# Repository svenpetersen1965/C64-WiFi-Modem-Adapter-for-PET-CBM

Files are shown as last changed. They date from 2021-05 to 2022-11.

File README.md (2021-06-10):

# C64-WiFi-Modem-Adapter for the Commodore PET/CBM computers
This is an adapter for connecting a <a href="https://github.com/svenpetersen1965/C64-WiFi-Modem-User-Port">C64 WiFi-Modem</a> to the PET/CBM User Port.

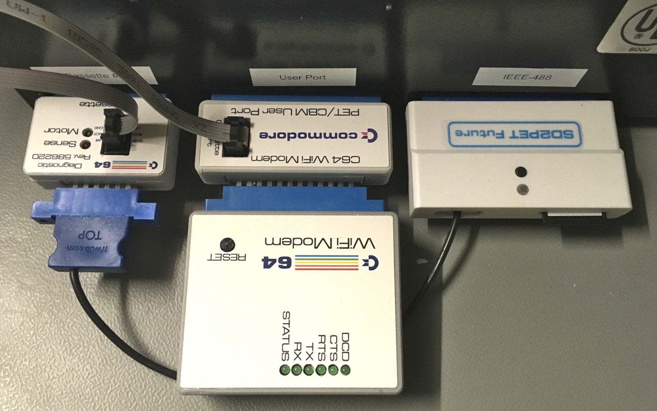
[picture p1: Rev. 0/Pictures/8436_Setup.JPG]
WiFi-modem on CBM8032


The power obtained from the Cassette Port via the <a href="https://github.com/svenpetersen1965/C64-Diagnostic-Rev.-586220-Harness/tree/master/Diag586220_Harness/Diag586220_Cassette_Port">Cassette Port Dongle</a> from the diagnostic harness for the C64.

The terminal program that was used for testing is <a href="https://github.com/ChartreuseK/PETTERM/releases">PETTERM0.5.0</a>

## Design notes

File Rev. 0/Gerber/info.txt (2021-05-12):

      
       Board: Wifi_Modem_PET_Adapter
       Rev.:  0
  
       Files:
       ======
  
       All Gerber files are generated in extended gerber format (RS274X)
       *.TOP        : Film top copper
       *.BOT        :  -"- bottom copper
       *.STC        :  -"- top soldermask 
       *.STS        :  -"- bottom soldermask
       *.PLC        :  -"- silk screen top
       *.DK         : Drills plated Through (Excellon)
       *.NDK        : Drills not plated Through (Excellon)
       *.OUT        : Board outline

       Board Size:
       ===========
       Length     :   54.0 mm
       Width      :   48.0 mm
       Thickness  :   1.6 mm
       Material   :   FR 4
       Copper     :   35 um
       Surface    :   HASL
       
       Remarks:
       ========
       Width >= 8mil
       Distance >= 6mil
       Drill >= 0.35mm

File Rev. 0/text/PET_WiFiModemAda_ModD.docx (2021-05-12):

Commodore C64 WiFi-Modem PET Adapter Rev. 0
Module Description

The C64 WiFi-Modem Adapter for PET was made to connect the C64 WiFi-Modem (https://1200baud.wordpress.com/2017/03/04/build-your-own-9600-baud-c64-wifi-modem-for-20/), (project on github.com) (https://github.com/svenpetersen1965/C64-WiFi-Modem-User-Port) to the User Port of the Commodore PET or CBM.


Figure 1: Setup with cassette dongle, user port adapter, WiFi modem and SD2PET

The wiring is done according to the requirements of the terminal program PETTERM 0.5.0 (https://github.com/ChartreuseK/PETTERM/releases).

Modem Signal | PET User Port | Direction (seen from PET) | PET UP Pin | C64 Modem | Modem Pin
TxD | CA1 & PA0 | input | B & C | Flag & PB0 | B & C
RxD | CB2 | output | M | PA2 | M

The signals RTS, DCD and CTS are not used, neither by the modem nor by PETTERM.

To provide an upgrade in future, the unused PET User Port pins and the signals mentioned before, are connected to a pin header (for jumpering).

Pin | PET Userport | JP1 | JP1 | C64 WiFi Modem | Pin
D | PA1 | 13 | 14 | RTS | D
E | PA2 | 11 | 12 | - | -
F | PA3 | 9 | 10 | - | -
H | PA4 | 7 | 8 | DCD | H
J | PA5 | 5 | 6 | - | -
K | PA6 | 3 | 4 | CTS | K
L | PA7 | 1 | 2 | - | -

Since the PET User Port does not provide +5V for powering the modem, this voltage is tapped from the Cassette Port and a cassette port dongle (https://github.com/svenpetersen1965/C64-Diagnostic-Rev.-586220-Harness/tree/master/Diag586220_Harness/Diag586220_Cassette_Port), which is also used in the C64 Diagnostic Harness. The connection is achieved with a 2x3 pin header (J3) and a ribbon cable.

Signal | Pin | Pin | Signal
GND | 1 | 2 | +5V
- | 3 | 4 | -
- | 5 | 6 | -

There is also a barrel connector for the +5V (5.5/2.1mm), which is not recommended to use, since it might collide with an IEEE-488 port connector/device.

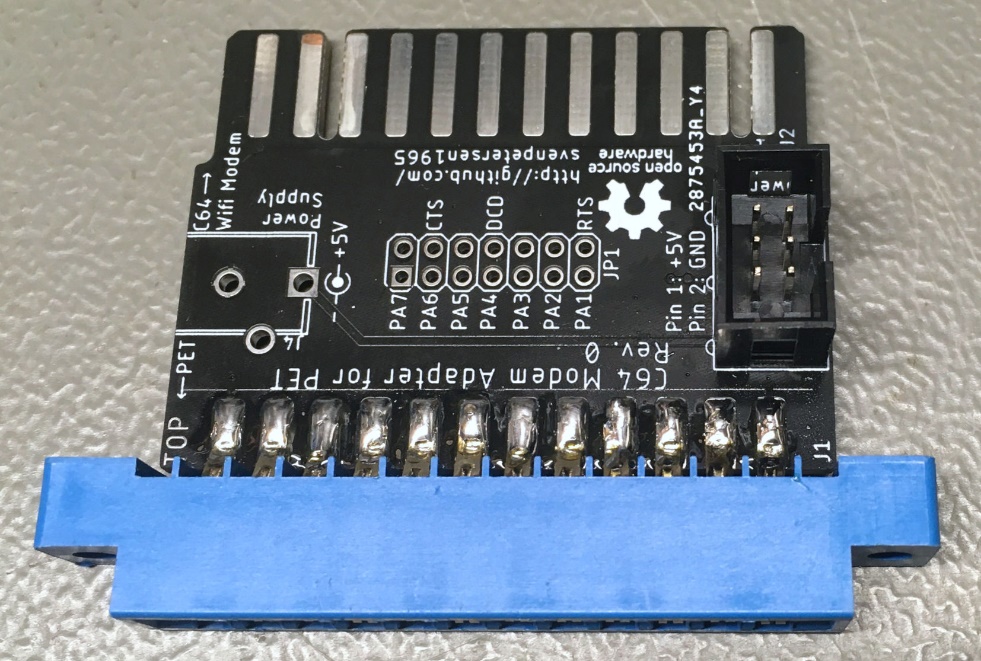
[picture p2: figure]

Figure 2: assembled PCB of the WiFi modem adapter

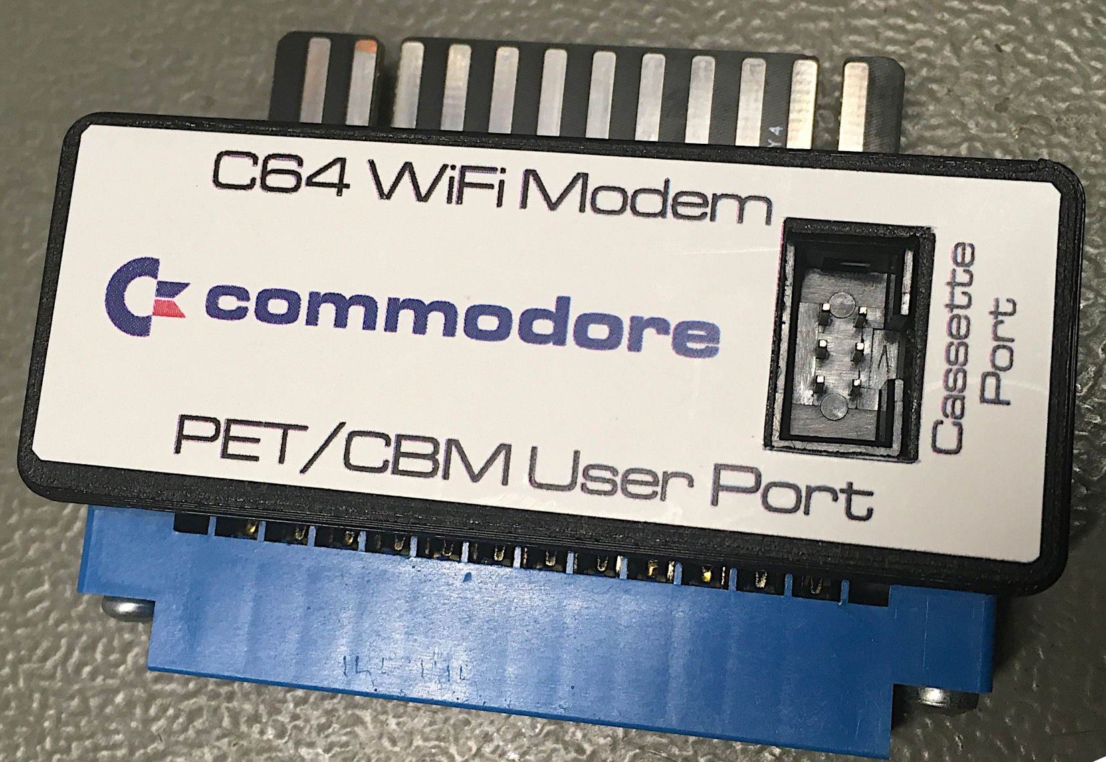
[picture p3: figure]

Figure 3: Adapter in 3D printed case

The screws recommended for the 3D printed case are

- 2x C2.9x9.5 DIN 7981 (for connecting bottom shell and top shell of the case)
- 2x C2.9x13 DIN 7981 (for attaching the edge connector to the bottom shell)

Other screws of approximately the same dimensions might work as well.

# Dimensions

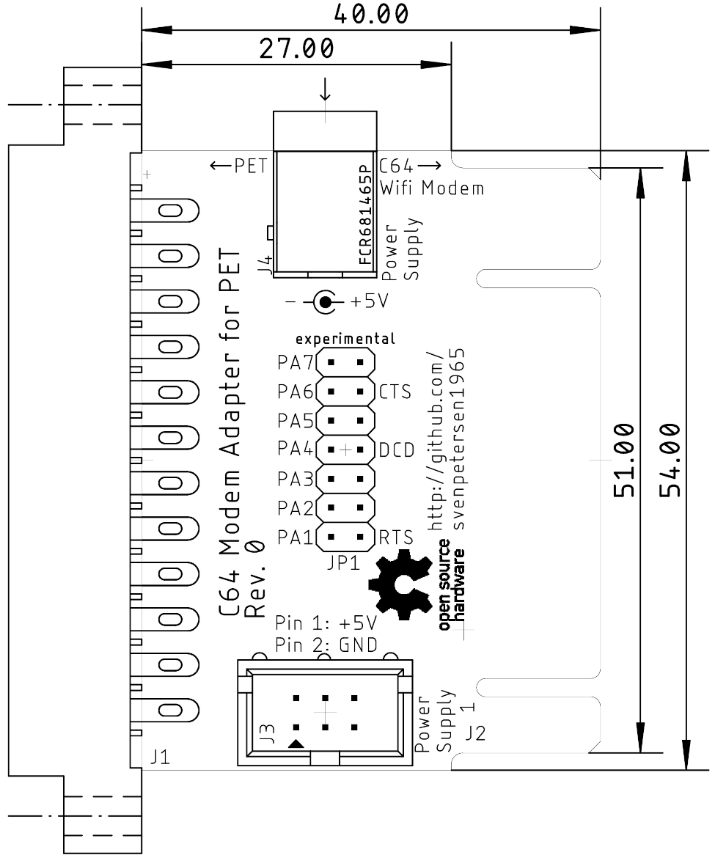
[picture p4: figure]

# Revision History

## Rev. 0

- Fully functional prototype

PET_WiFiModemAda_ModD.docx 12.05.2021 21:18 Drafted by Sven Petersen Page 2 of 2 Doc.-No.: 175-6-01-00

PET_WiFiModemAda_ModD.docx 12.05.2021 21:18 Drafted by Sven Petersen Page 1 of 1 Doc.-No.: 000-6-00-00

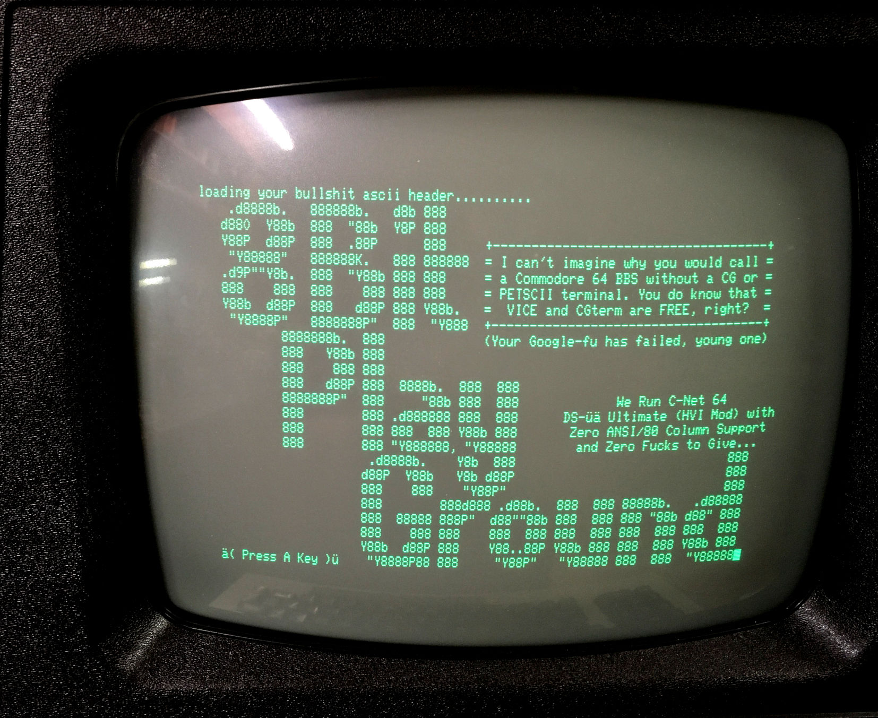
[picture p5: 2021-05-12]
Rev. 0/Pictures/8157_-_8bit_Playground.JPG

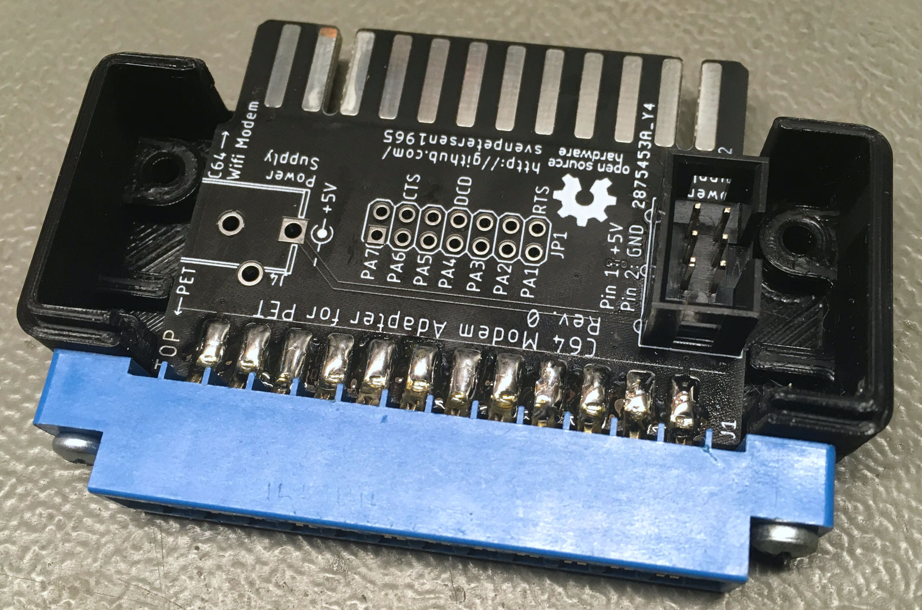
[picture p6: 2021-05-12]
Rev. 0/Pictures/8442_-_Adapter_in_bottom_sell.JPG

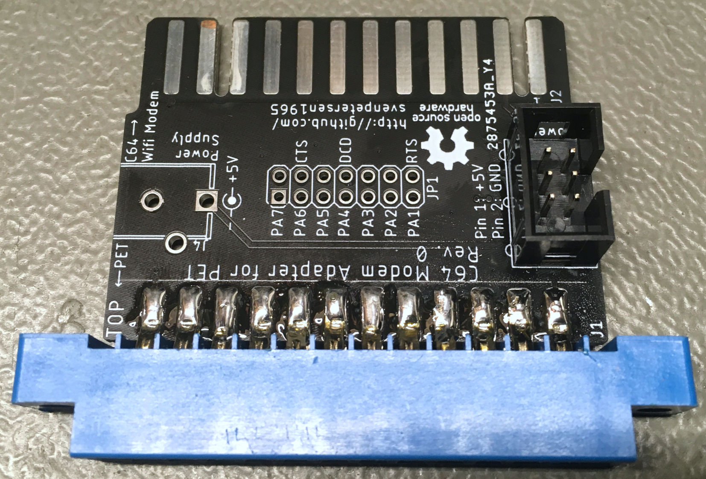
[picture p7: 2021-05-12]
Rev. 0/Pictures/8440_-_Adapter.JPG

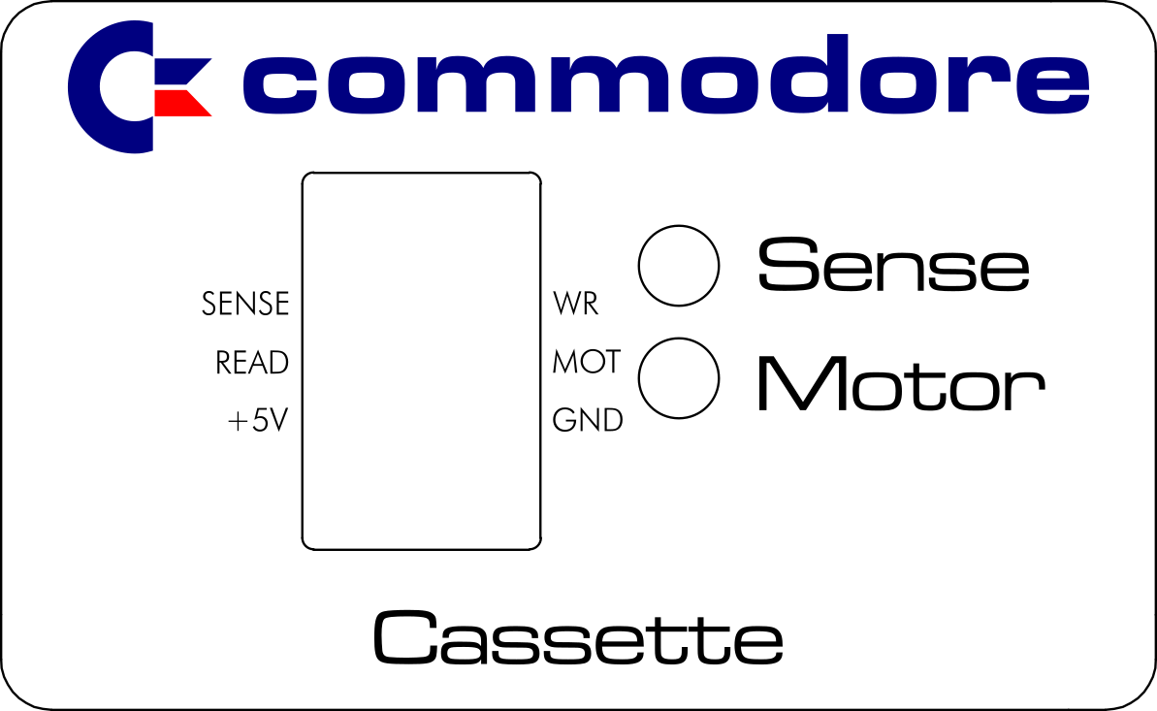
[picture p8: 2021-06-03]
3D-Case/Rev. 0/label/Cassette_Port_Dongle_Label.png

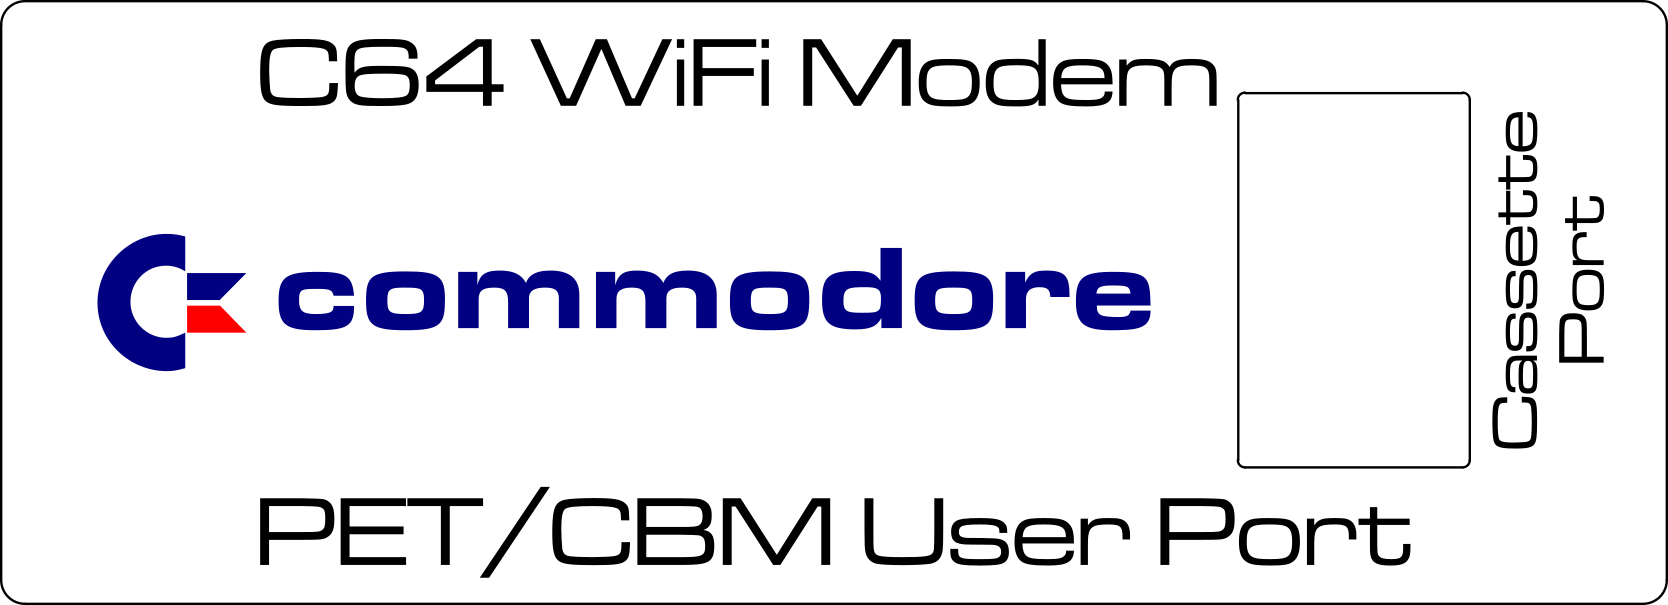
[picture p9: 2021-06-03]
3D-Case/Rev. 0/label/C64_WiFi_PET_Adapter_Label.png

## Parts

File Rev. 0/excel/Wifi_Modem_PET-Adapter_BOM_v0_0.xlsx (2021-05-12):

Commodore C64 Wifi-Modem PET Adapter Rev. 0
Bill of Material Rev. 0.0
Pos. | Qty | Value | Footprint | Ref.-No. | Comment
1 | 1 | 175-2-01-00 | 2 Layer | PCB Rev. 0 | 2 layer, Cu 35µ, HASL, 54.0mm x 40.0mm, 1.6mm FR4
2 | 1 | 2x3 box header, 2.54mm | 2X03WV | J3 | e.g. Reichelt WSL 6G
3 | 1 | 2x07, pinheader, 2.54mm | 2X07 | JP1 | Do not place
4 | 1 | FCR681465P | FCR681465P | J4 | Cliff. Do not place!
5 | 1 | Edge connector, 2x12, 3.96mm | USERPORT | J1 | edge connector, C64 user port, series 805

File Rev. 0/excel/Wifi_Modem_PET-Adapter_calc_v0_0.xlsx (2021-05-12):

Commodore C64 Wifi-Modem PET Adapter Rev. 0
Bill of Material Rev. 0.0
Pos. | Qty | Value | €/ea | € | Comment
1 | 1 | 175-2-01-00 | 1.00 € | 1.00 € | 2 layer, Cu 35µ, HASL, 54.0mm x 40.0mm, 1.6mm FR4
2 | 1 | 2x3 box header, 2.54mm | 0.25 € | 0.25 € | e.g. Reichelt WSL 6G
3 | 0 | 2x07, pinheader, 2.54mm | 0.32 € | 0.00 € | Do not place
4 | 0 | FCR681465P | 1.10 € | 0.00 € | Cliff. Do not place!
5 | 1 | Edge connector, 2x12, 3.96mm | 3.00 € | 3.00 € | edge connector, C64 user port, series 805
 |  | Total |  | 4.25 €

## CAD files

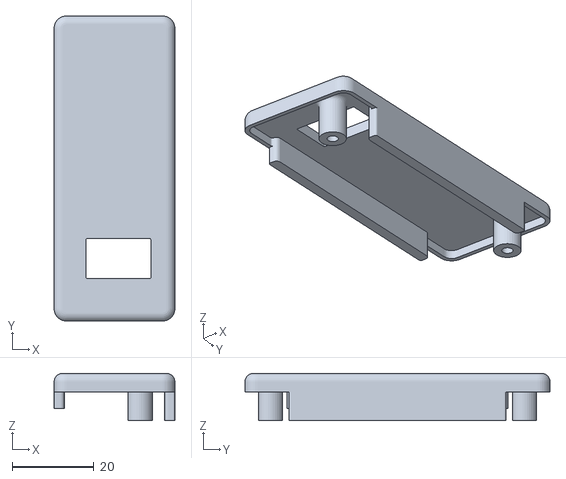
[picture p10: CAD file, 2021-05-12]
3D-Case/Rev. 0/stl/PETAda_top_shell.stl
29.5 x 74.5 x 11.5

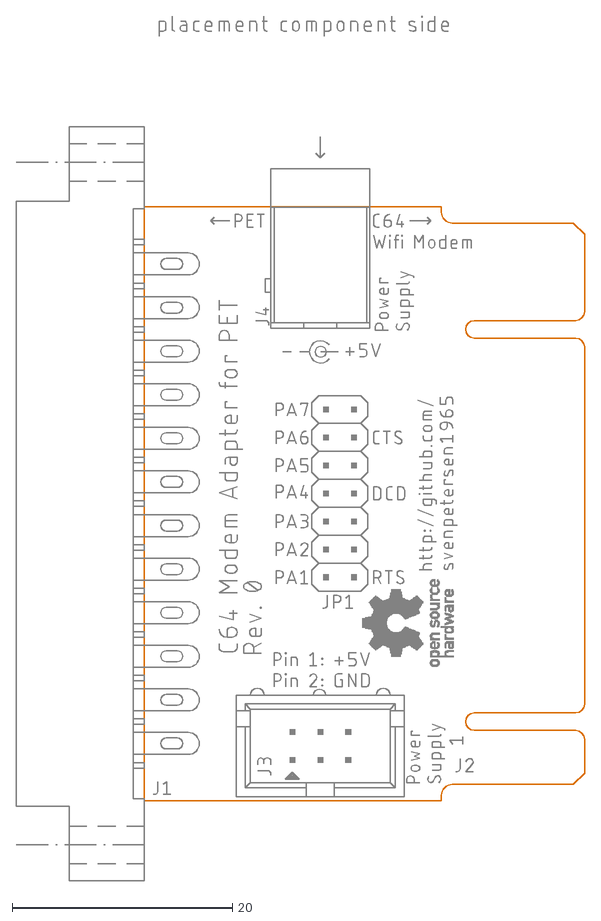
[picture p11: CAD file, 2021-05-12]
Rev. 0/dxf/Wifi_Modem_PET-Adapter.dxf
51.6 x 78.5

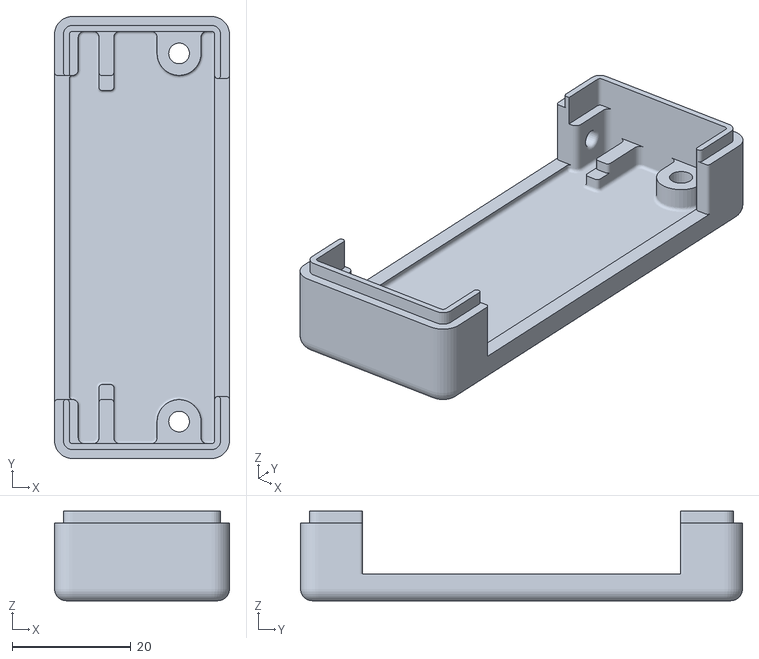
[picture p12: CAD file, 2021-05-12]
3D-Case/Rev. 0/stl/PETAda_bottom_shell.stl
29.5 x 74.5 x 15.1

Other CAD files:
3D-Case/Rev. 0/Fusion360/C64_Wifi_PET_adapter v4.f3d

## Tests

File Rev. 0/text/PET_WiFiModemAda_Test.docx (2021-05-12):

Commodore C64 WiFi-Modem PET Adapter Rev. 0
Testing

# Test Setup

The Test was conducted on a CBM8032 with a German character set, a C64 WiFi-Modem (like mentioned in Document 175-6-01-**), a Cassette Port dongle Rev. 1 and a C64 WiFi-Modem Adapter Rev. 0. The software PETTERM0-5-0 was stored on an SD-card in the SD2PET future.


Figure 1: Test Setup

The baud rate of the modem was set to 1200baud (this configuration was done and stored with the software CSMG2017 running on a C64).

# Test Execution

Several BBSes have been called. The WiFi-Modem has been fully operational at all time, the information transfer was correct.

# Conclusion

The WiFi-Modem Adapter is fully functional.


Figure 2: CBM8032 connected to the BBS 8Bit Playground

PET_WiFiModemAda_Test.docx 12.05.2021 21:54 Drafted by Sven Petersen Page 2 of 2 Doc.-No.: 175-6-02-00

PET_WiFiModemAda_Test.docx 12.05.2021 21:54 Drafted by Sven Petersen Page 1 of 1 Doc.-No.: 175-6-02-00

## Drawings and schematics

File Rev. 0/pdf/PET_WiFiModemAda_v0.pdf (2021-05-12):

# Project Documentation

## Commodore C64 Wifi-Modem PET Adapter

## Project number: 175

## Revision: 0

## Date: 10.03.2021

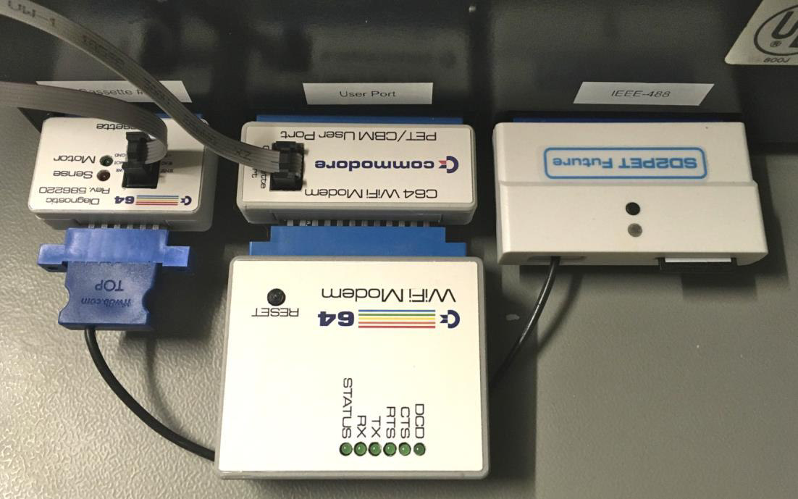
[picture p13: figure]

PET_WiFiModemAda_ModD.docx | | 12.05.2021 21:18
Drafted by Sven Petersen | Page 1 of 3 | Doc.-No.: 175-6-01-00

### Commodore C64 WiFi-Modem PET Adapter Rev. 0

### Module Description

The C64 WiFi-Modem Adapter for PET was made to connect the C64 WiFi-Modem (https://1200baud.wordpress.com/2017/03/04/build-your-own-9600-baud-c64-wifi-modem-for-20/), (https://1200baud.wordpress.com/2017/03/04/build-your-own-9600-baud-c64-wifi-modem-for-20/) (project on github.com) (https://github.com/svenpetersen1965/C64-WiFi-Modem-User-Port) to the User Port of the Commodore PET or CBM.

Figure 1: Setup with cassette dongle, user port adapter, WiFi modem and SD2PET

The wiring is done according to the requirements of the terminal program PETTERM 0.5.0. (https://github.com/ChartreuseK/PETTERM/releases)

Modem
Signal
PET User Port | Direction (seen from PET)

PET UP
Pin

C64 Modem Modem Pin

TxD | CA1 & PA0 | input | B & C | Flag & PB0 | B & C
RxD | CB2 | output | M | PA2 | M

The signals RTS, DCD and CTS are not used, neither by the modem nor by PETTERM.

To provide an upgrade in future, the unused PET User Port pins and the signals mentioned before, are connected to a pin header (for jumpering).

Pin PET Userport JP1 | JP1 C64 WiFi Modem Pin
D | PA1 | 13 | 14 | RTS | D
E | PA2 | 11 | 12 | - | -
F | PA3 | 9 | 10 | - | -
H | PA4 | 7 | 8 | DCD | H
J | PA5 | 5 | 6 | - | -
K | PA6 | 3 | 4 | CTS | K
L | PA7 | 1 | 2 | - | -

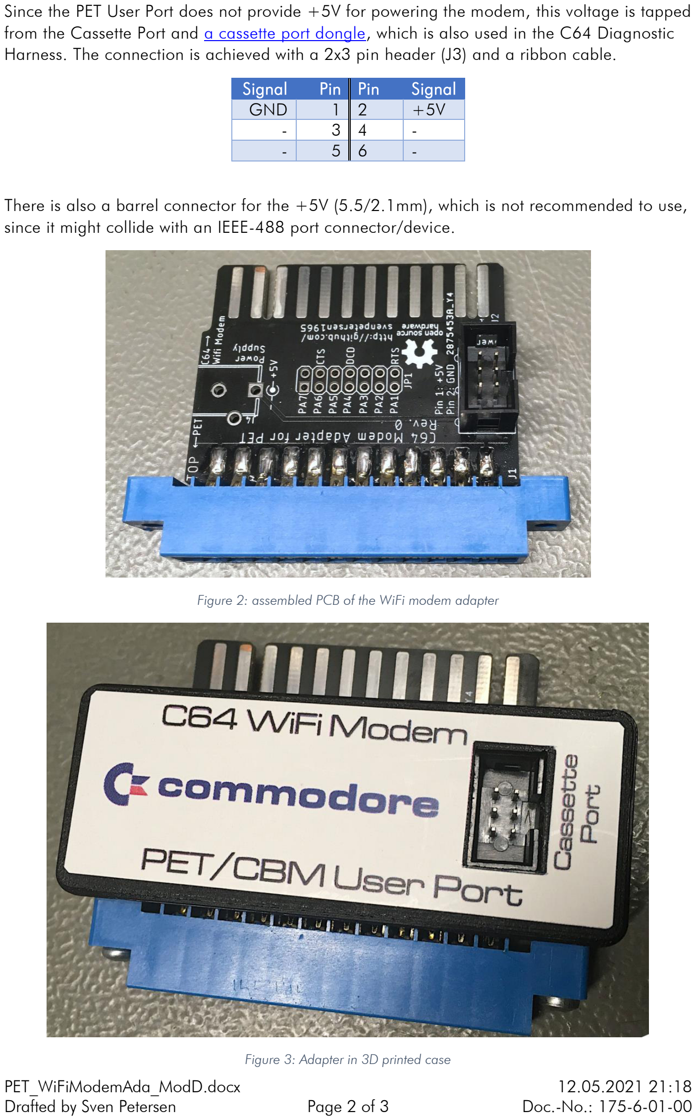
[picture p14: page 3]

PET_WiFiModemAda_ModD.docx | | 12.05.2021 21:18
Drafted by Sven Petersen | Page 2 of 3 | Doc.-No.: 175-6-01-00

Since the PET User Port does not provide +5V for powering the modem, this voltage is tapped from the Cassette Port and a cassette port dongle, (https://github.com/svenpetersen1965/C64-Diagnostic-Rev.-586220-Harness/tree/master/Diag586220_Harness/Diag586220_Cassette_Port) which is also used in the C64 Diagnostic Harness. The connection is achieved with a 2x3 pin header (J3) and a ribbon cable.

Signal Pin | Pin Signal
GND | 1 | 2 | +5V
- | 3 | 4 | -
- | 5 | 6 | -

There is also a barrel connector for the +5V (5.5/2.1mm), which is not recommended to use, since it might collide with an IEEE-488 port connector/device.

Figure 2: assembled PCB of the WiFi modem adapter

Figure 3: Adapter in 3D printed case

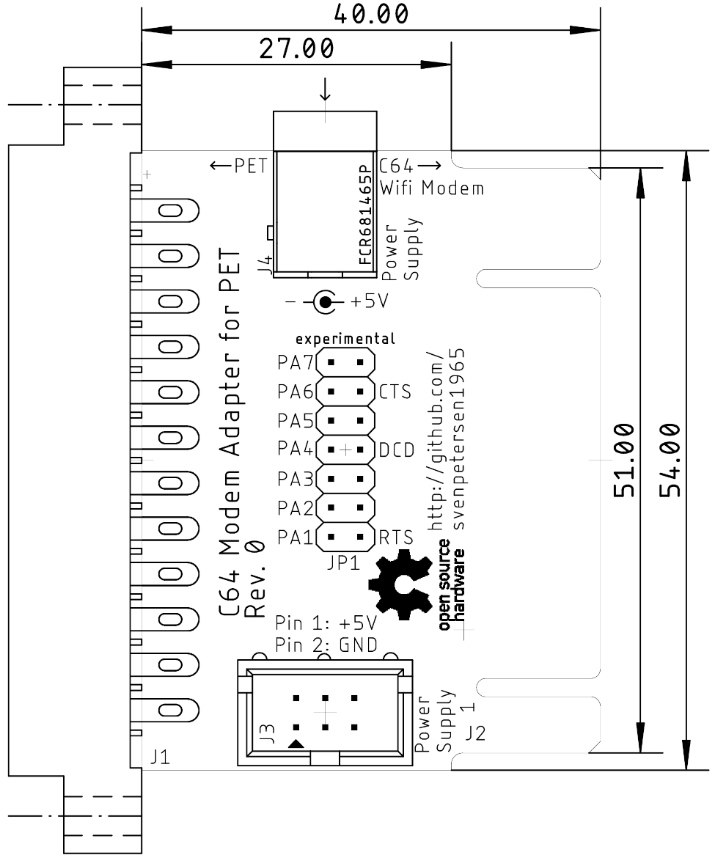
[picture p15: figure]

PET_WiFiModemAda_ModD.docx | | 12.05.2021 21:18
Drafted by Sven Petersen | Page 3 of 3 | Doc.-No.: 175-6-01-00

The screws recommended for the 3D printed case are

- 2x C2.9x9.5 DIN 7981 (for connecting bottom shell and top shell of the case)
- 2x C2.9x13 DIN 7981 (for attaching the edge connector to the bottom shell)

Other screws of approximately the same dimensions might work as well.

## Dimensions

## Revision History

### Rev. 0

- Fully functional prototype

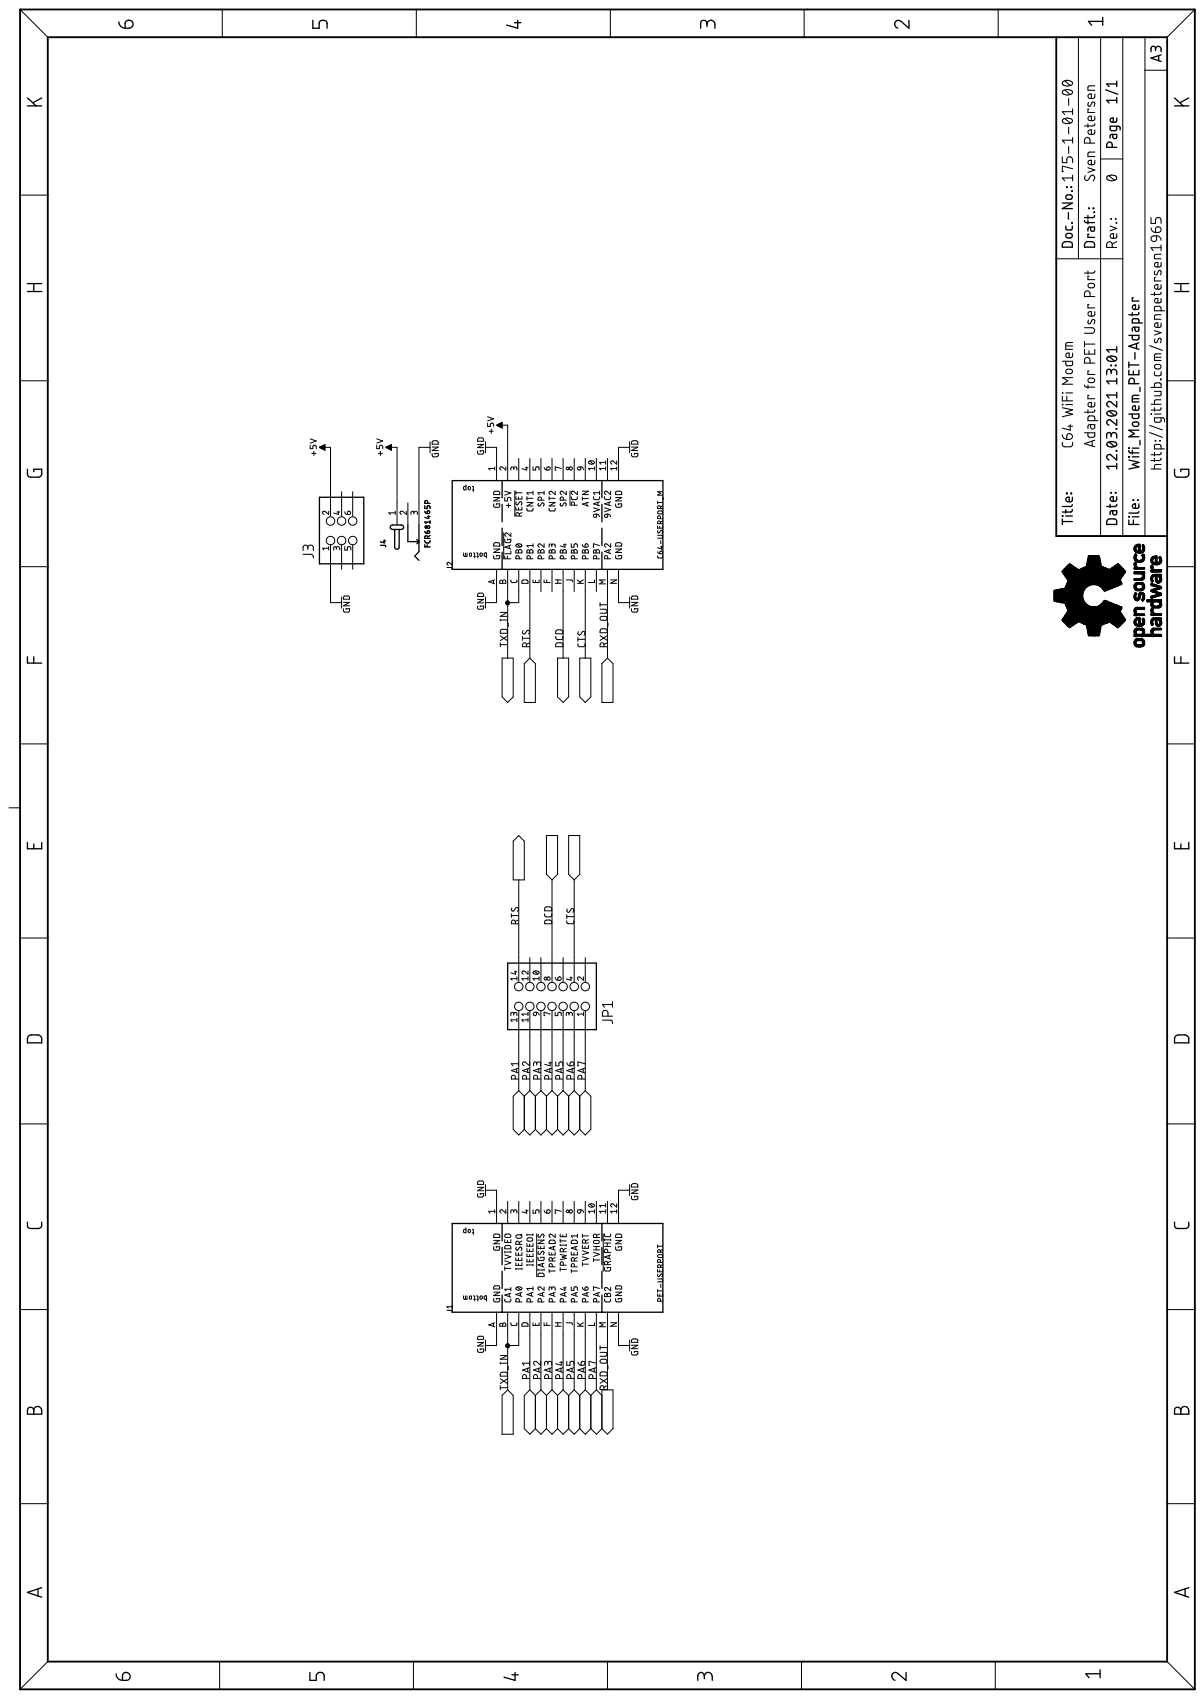
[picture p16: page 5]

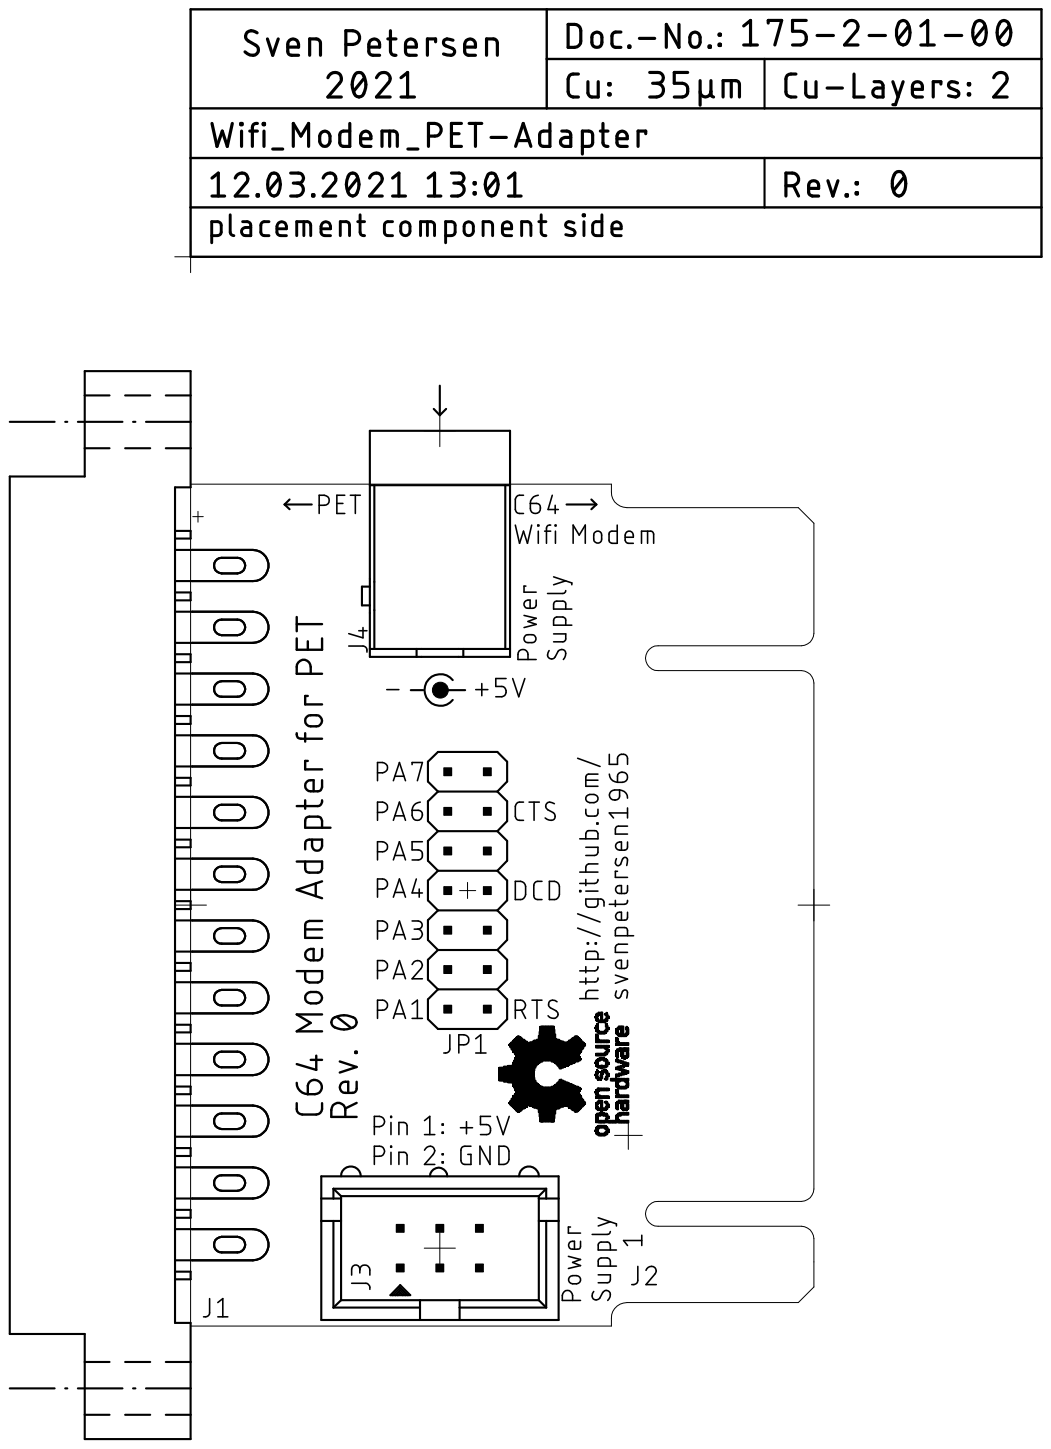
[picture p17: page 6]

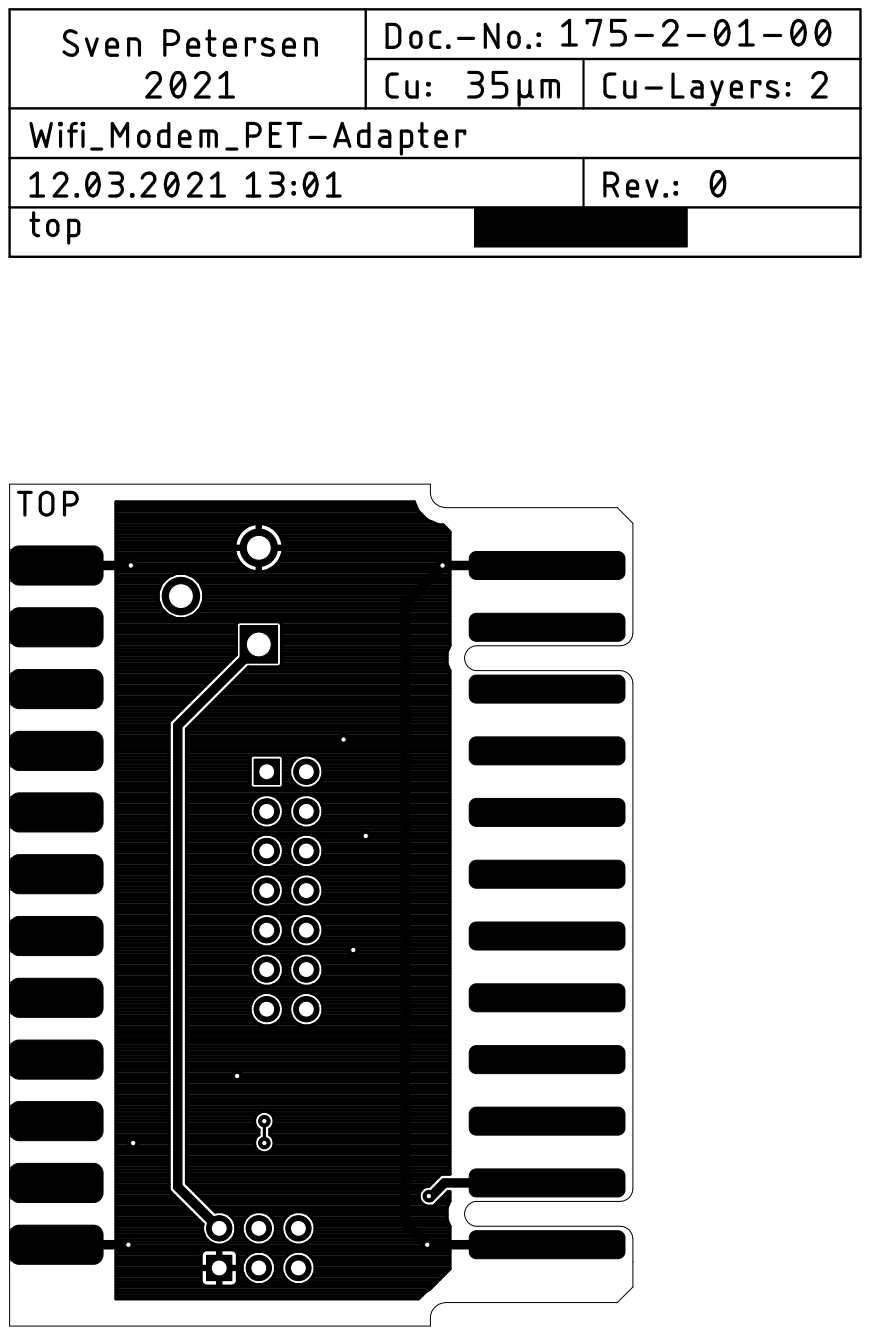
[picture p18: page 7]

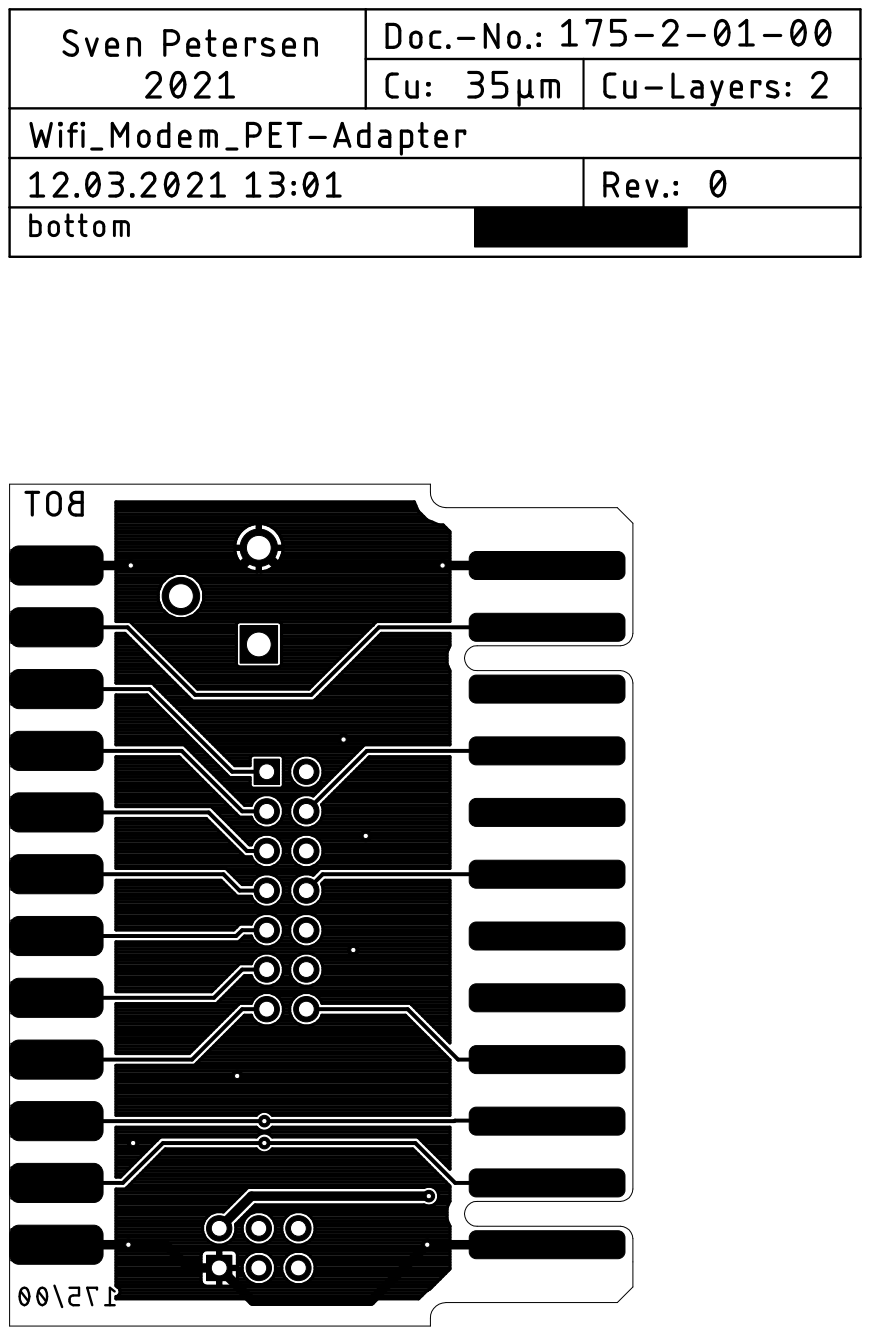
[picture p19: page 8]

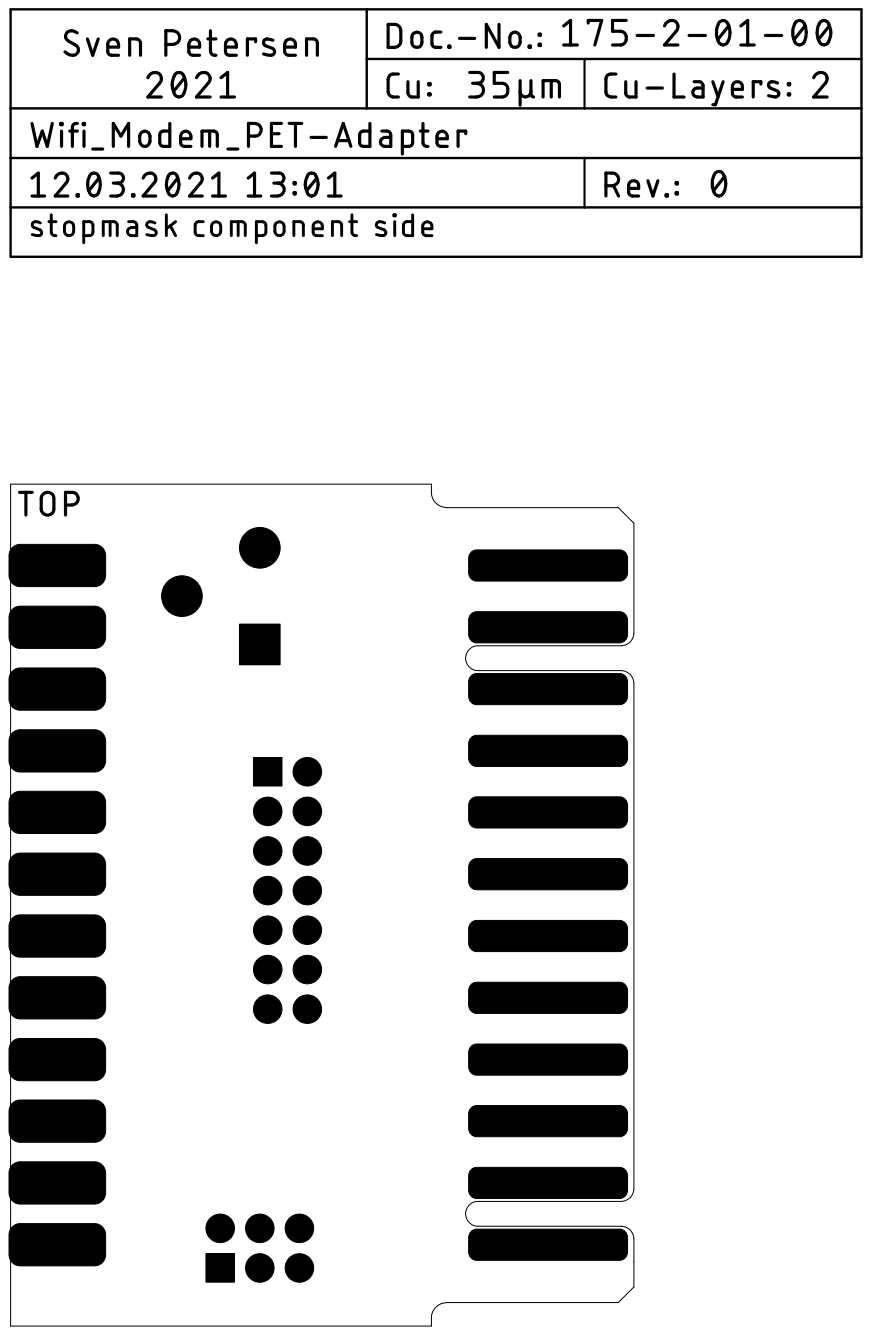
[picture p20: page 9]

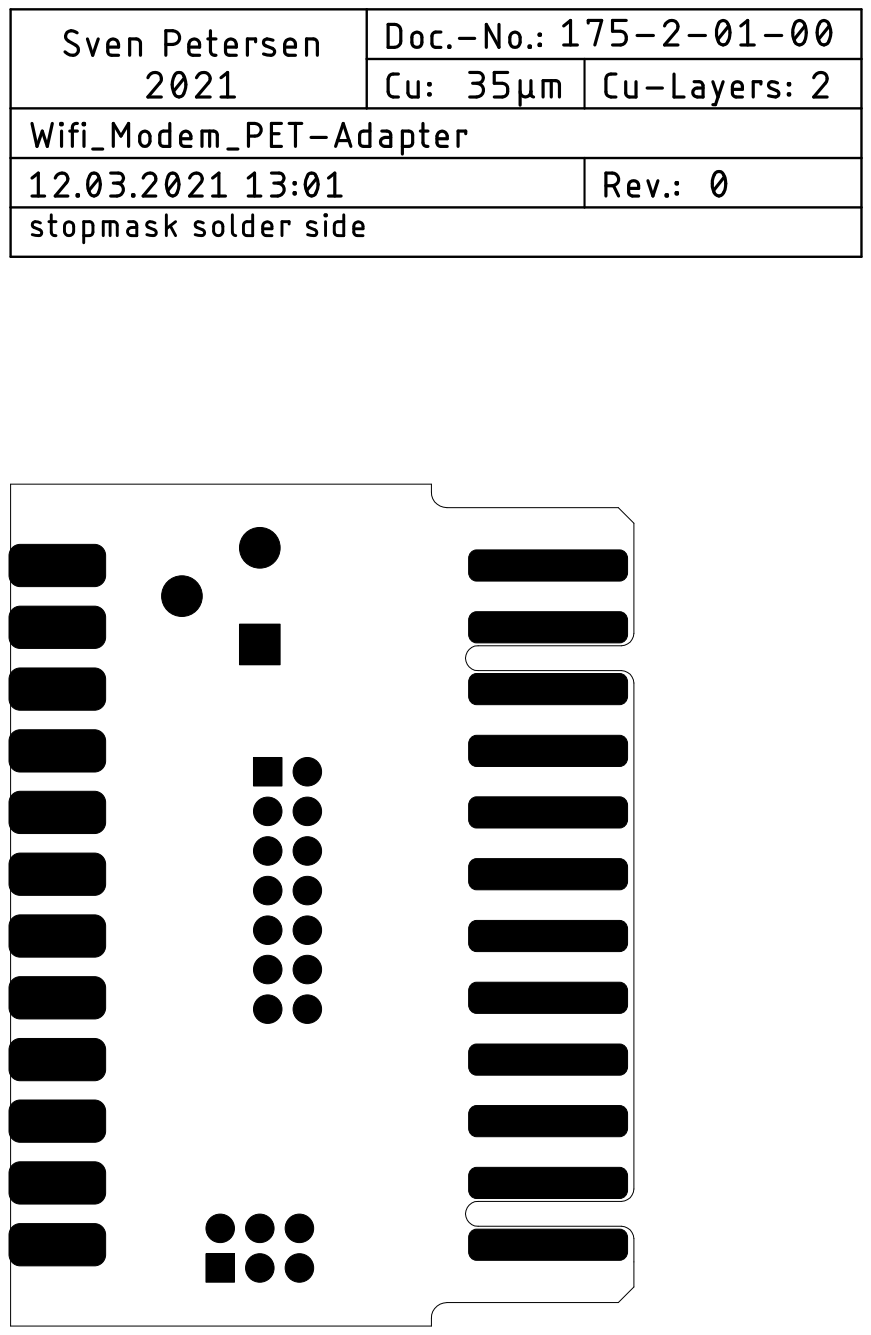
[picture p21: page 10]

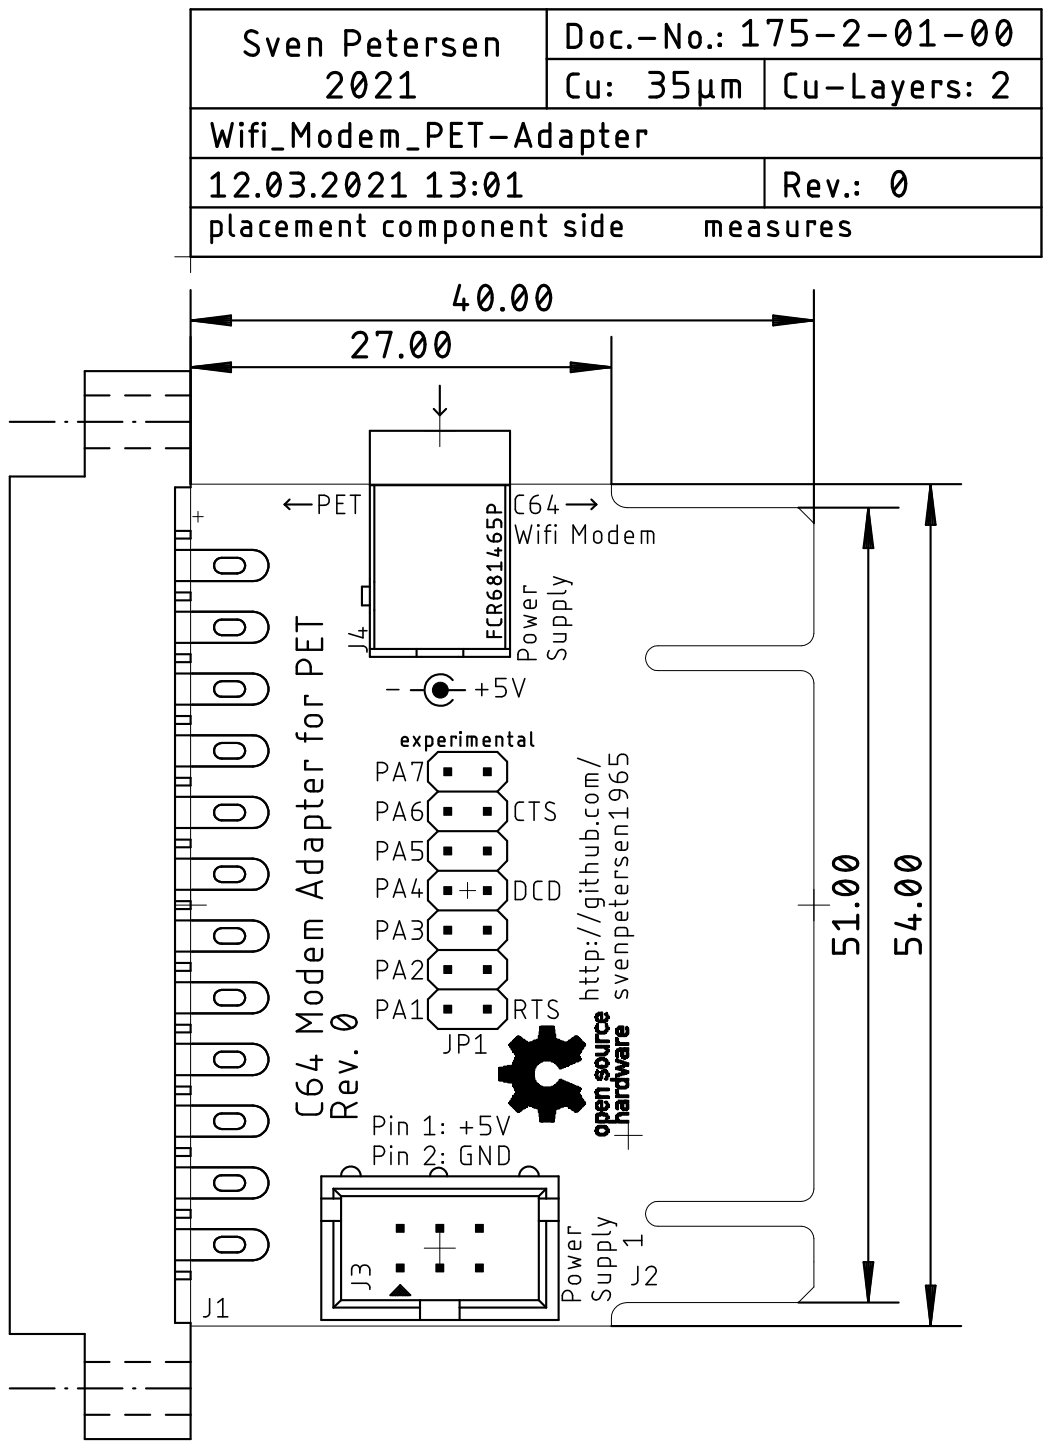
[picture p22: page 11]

PET_WiFiModemAda_Test.docx | | 12.05.2021 21:54
Drafted by Sven Petersen | Page 1 of 2 | Doc.-No.: 175-6-02-00

### Commodore C64 WiFi-Modem PET Adapter Rev. 0

### Testing

## Test Setup

The Test was conducted on a CBM8032 with a German character set, a C64 WiFi-Modem (like mentioned in Document 175-6-01-**), a Cassette Port dongle Rev. 1 and a C64 WiFi-Modem Adapter Rev. 0. The software PETTERM0-5-0 was stored on an SD-card in the SD2PET future.

Figure 1: Test Setup

The baud rate of the modem was set to 1200baud (this configuration was done and stored with the software CSMG2017 running on a C64).

## Test Execution

Several BBSes have been called. The WiFi-Modem has been fully operational at all time, the information transfer was correct.

## Conclusion

The WiFi-Modem Adapter is fully functional.

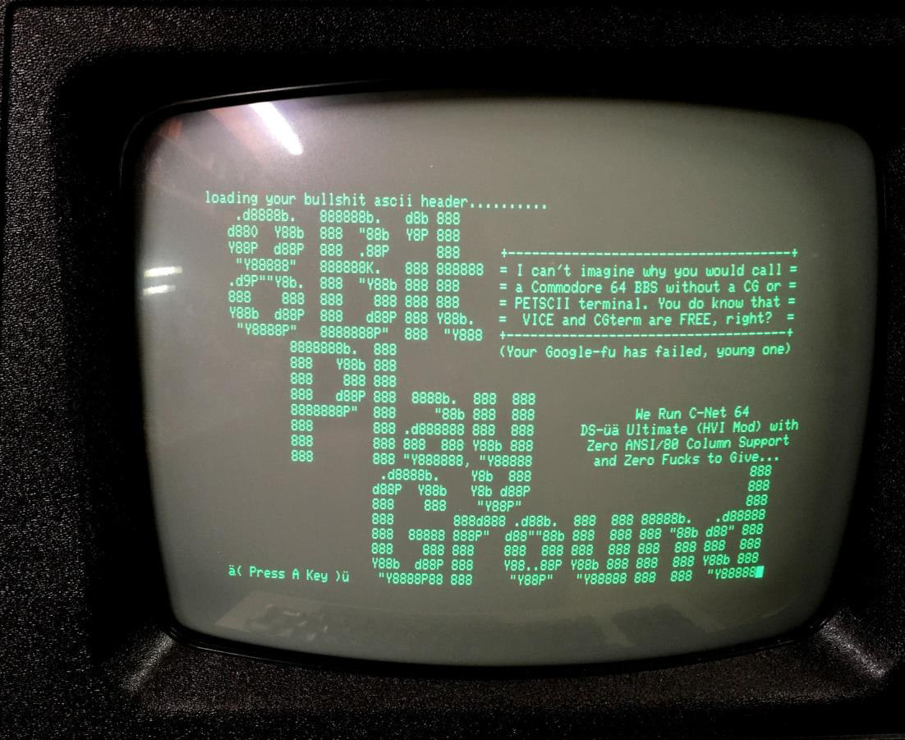
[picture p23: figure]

PET_WiFiModemAda_Test.docx | | 12.05.2021 21:54
Drafted by Sven Petersen | Page 2 of 2 | Doc.-No.: 175-6-02-00

Figure 2: CBM8032 connected to the BBS 8Bit Playground

Pos. Qty Value Footprint Ref.-No. Comment

1 1 175-2-01-00 2 Layer PCB Rev. 0 2 layer, Cu 35µ, HASL, 54.0mm x 40.0mm, 1.6mm FR4

2 1 2x3 box header, 2.54mm 2X03WV J3 e.g. Reichelt WSL 6G

3 1 2x07, pinheader, 2.54mm 2X07 JP1 Do not place

4 1 FCR681465P FCR681465P J4 Cliff. Do not place!

5 1 Edge connector, 2x12,

3.96mm

USERPORT J1 edge connector, C64 user port, series 805

## Commodore C64 Wifi-Modem PET Adapter
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

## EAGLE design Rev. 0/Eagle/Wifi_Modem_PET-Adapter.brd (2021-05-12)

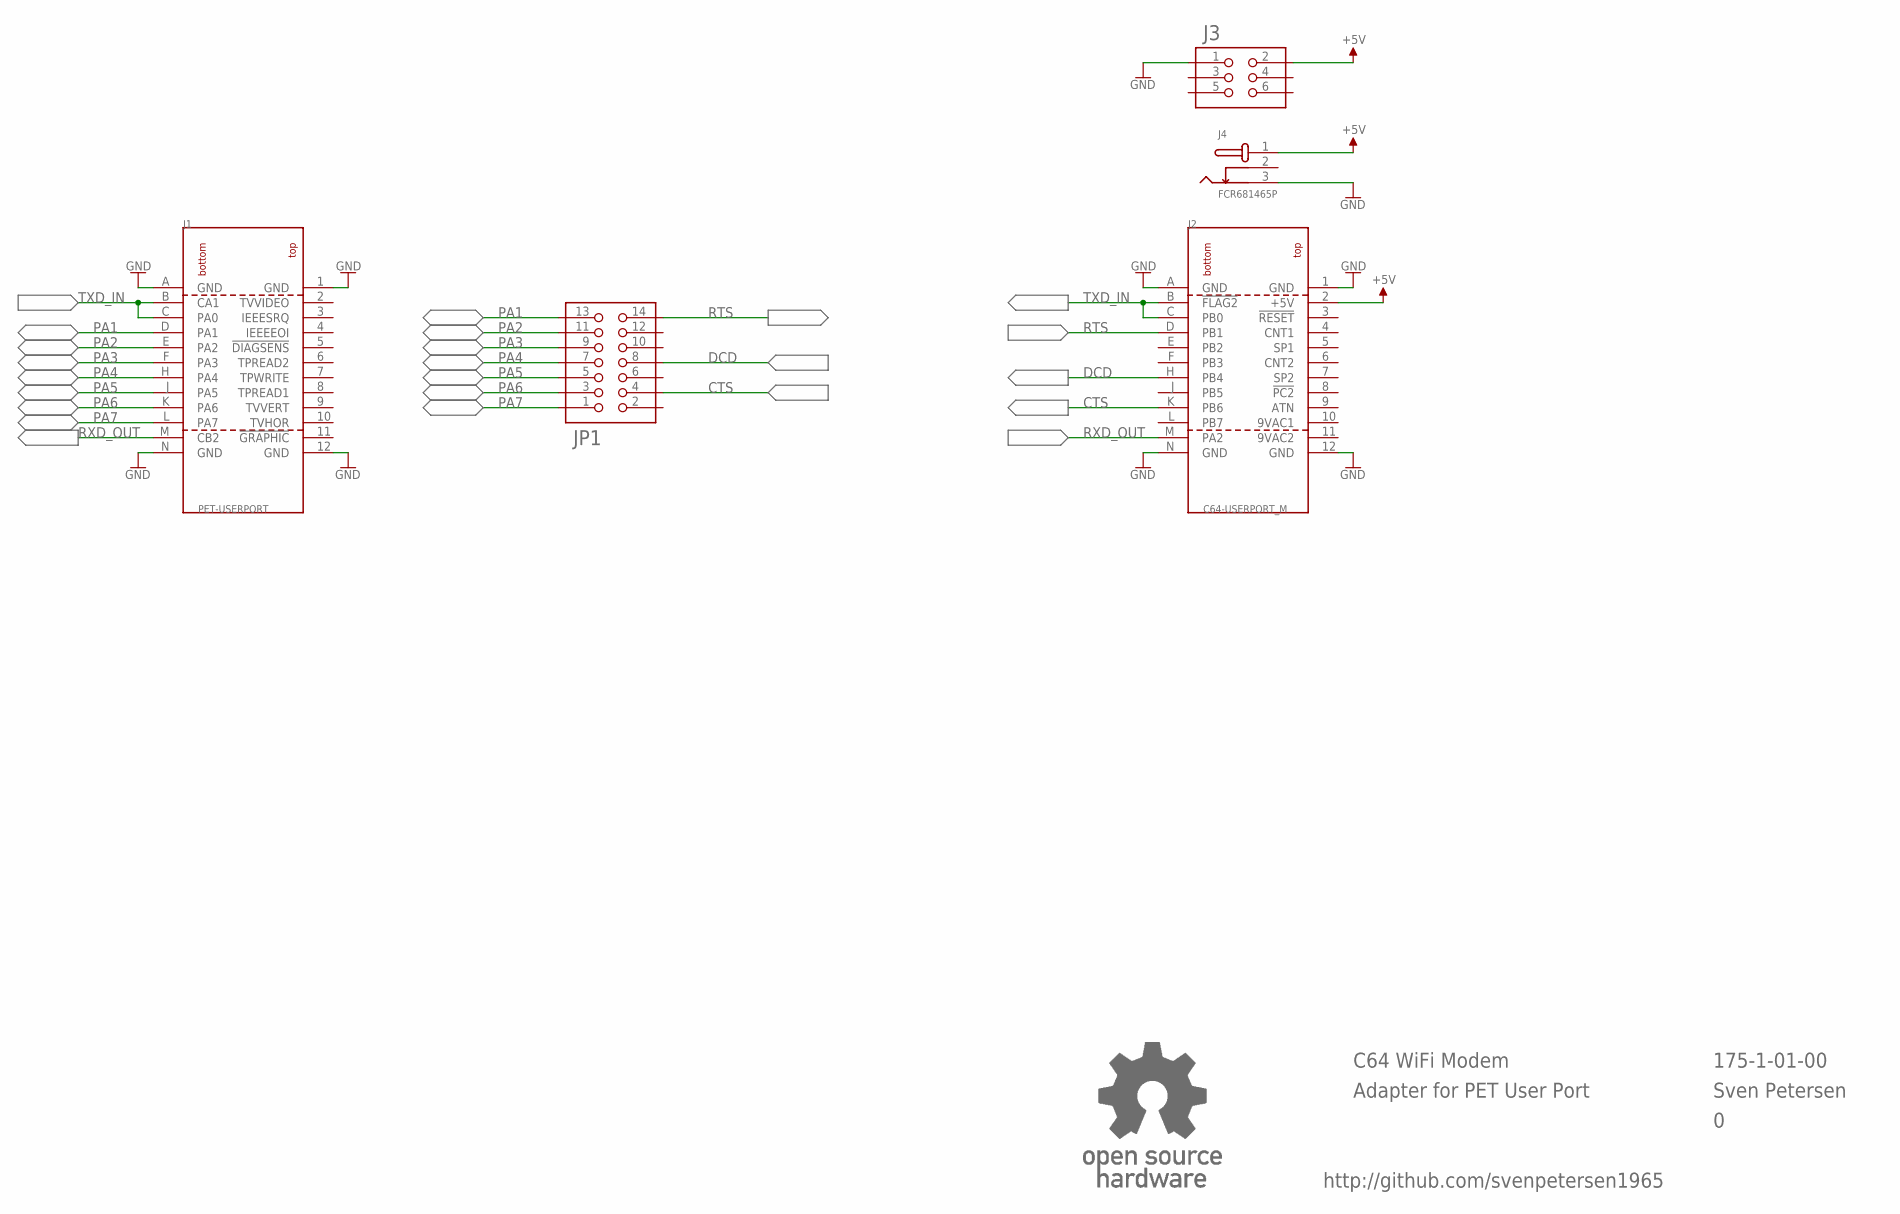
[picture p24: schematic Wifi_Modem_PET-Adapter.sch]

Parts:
J1: PET-USERPORT; USERPORT
J2: C64-USERPORT_M; USERPORT_M
J3: 2X03WV
J4: FCR681465P
JP1: PINHD-2X7; 2X07
U$2: OPEN_SOURCE_HW; OPENHW

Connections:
9VAC1: J2.10 (9VAC1)
9VAC2: J2.11 (9VAC2)
+5V: J2.2 (+5V), J3.2, J4.1
CTS: J2.K (PB6), JP1.4
DCD: J2.H (PB4), JP1.8
GND: J1.1 (GND), J1.12 (GND), J1.A (GND), J1.N (GND), J2.1 (GND), J2.12 (GND), J2.A (GND), J2.N (GND), J3.1, J4.3
PA1: J1.D (PA1), JP1.13
PA2: J1.E (PA2), JP1.11
PA3: J1.F (PA3), JP1.9
PA4: J1.H (PA4), JP1.7
PA5: J1.J (PA5), JP1.5
PA6: J1.K (PA6), JP1.3
PA7: J1.L (PA7), JP1.1
RTS: J2.D (PB1), JP1.14
RXD_OUT: J1.M (CB2), J2.M (PA2)
TXD_IN: J1.B (CA1), J1.C (PA0), J2.B (!FLAG2), J2.C (PB0)

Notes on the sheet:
C64 WiFi Modem
Adapter for PET User Port
Sven Petersen
175-1-01-00
http://github.com/svenpetersen1965

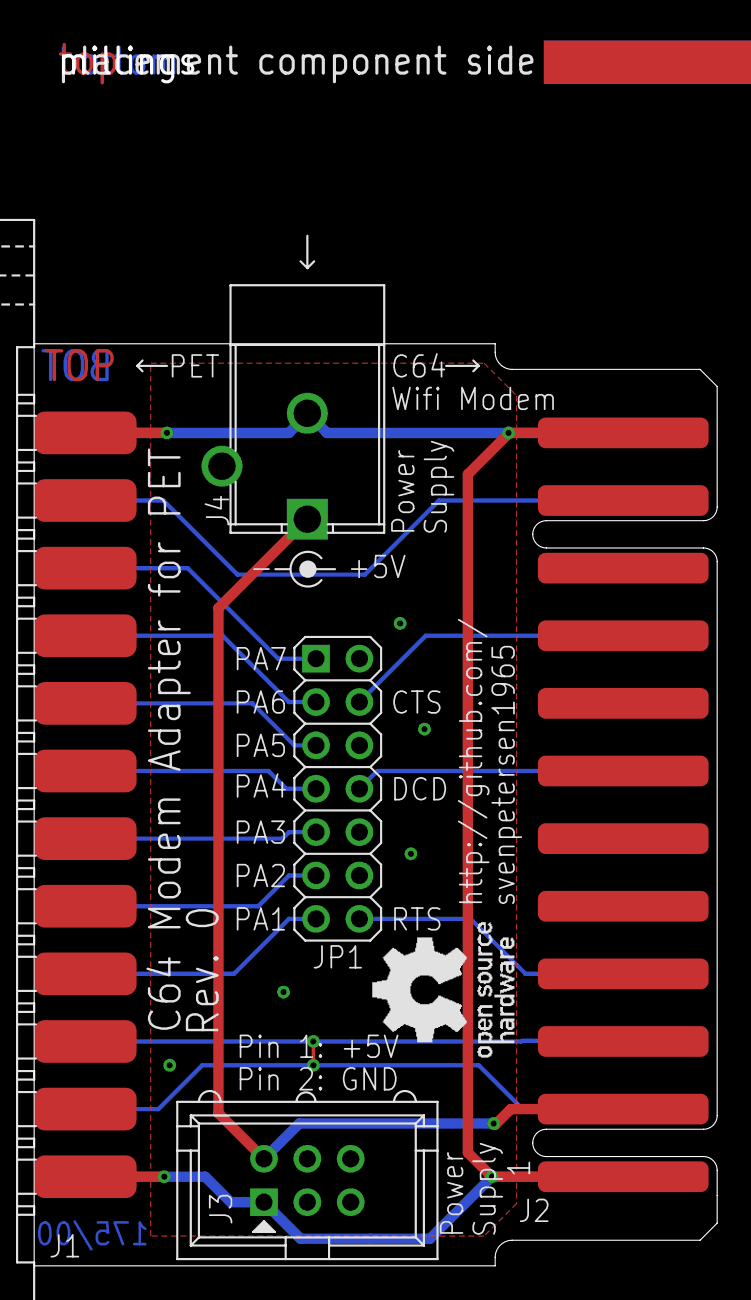
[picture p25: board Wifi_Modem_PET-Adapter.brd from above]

Board: 2 copper layers, 40.0 x 54.0 mm, 8 parts (0 on the bottom side), 14 nets.

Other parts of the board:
U$40: 2LAYER
U$41: PCB-TITLE/
